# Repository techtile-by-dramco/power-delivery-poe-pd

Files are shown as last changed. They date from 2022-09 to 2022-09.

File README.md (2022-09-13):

# Power delivery board 

This powered device (PD) board is made for the Techtile infrastructure and separates the voltage from the data coming from the ethernet CAT6 24AWG cable. It further converts the voltage to a lower usable 5V voltage with a galvanically isolated dc/dc converter (maximum output power 20W). This board is compatible with the IEEE802.3af/at/bt standard. 

To comply with the IEEE 802.3 standard a delay network was added. This prevents excessive startup power that occurs due to the high input capacitors of the DC/DC converters. During INRUSH state, the power may not exceed Power Class 3 (approximately 13W). Otherwise, the PSE may turn off the PD. (See standard and datasheet NCP1096)

Several USBs and connectors are available to power the peripherals on each tile.

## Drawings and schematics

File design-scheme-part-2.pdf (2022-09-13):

Q2G$1

Q2G$2

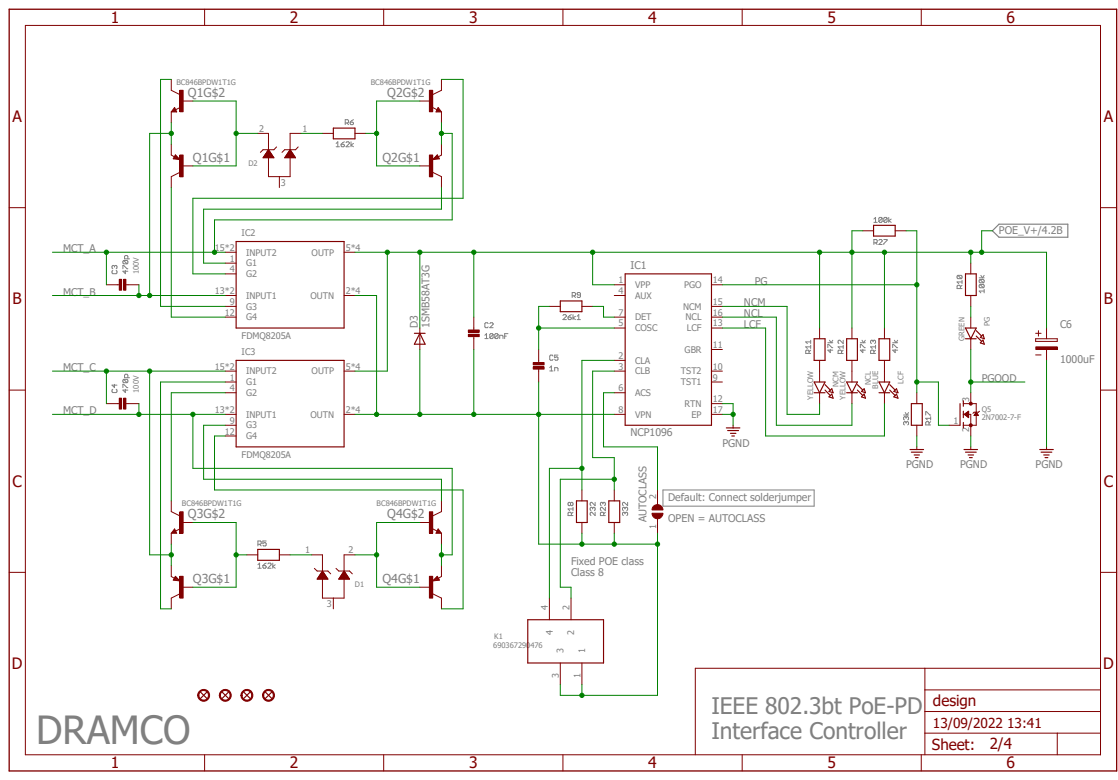
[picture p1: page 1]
NCP1096; BC846BPDW1T1G; BC846BPDW1T1G1SMB58AT3G; 2N7002-7-F PGND; PGND; PGND YELLOW; YELLOW; BLUE; GREEN; 690367290476 ¹⁰⁰V 100V; IEEE 802.3bt PoE-PD DRAMCO; Interface Controller; VPN 8; ACS 6; CLB 3; CLA 2; COSC 5; DET 7; VPP 1; PGO; NCM; NCL; LCF; GBR; AUX 4; RTN; TST2; TST1; INPUT2 15*2; INPUT1 13*2; OUTN; OUTP; FDMQ8205A; 1 2 3 NCM; PG AUTOCLASS 2 1; MCT_C; MCT_D; MCT_A; MCT_B; PGOOD; POE_V+/4.2B; design 13/09/2022 13:41 Sheet: 2/4

Default: Connect solderjumper
OPEN = AUTOCLASS

Fixed POE class
Class 8

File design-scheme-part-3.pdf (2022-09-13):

# 5V Connectors

# 5V FlyBack

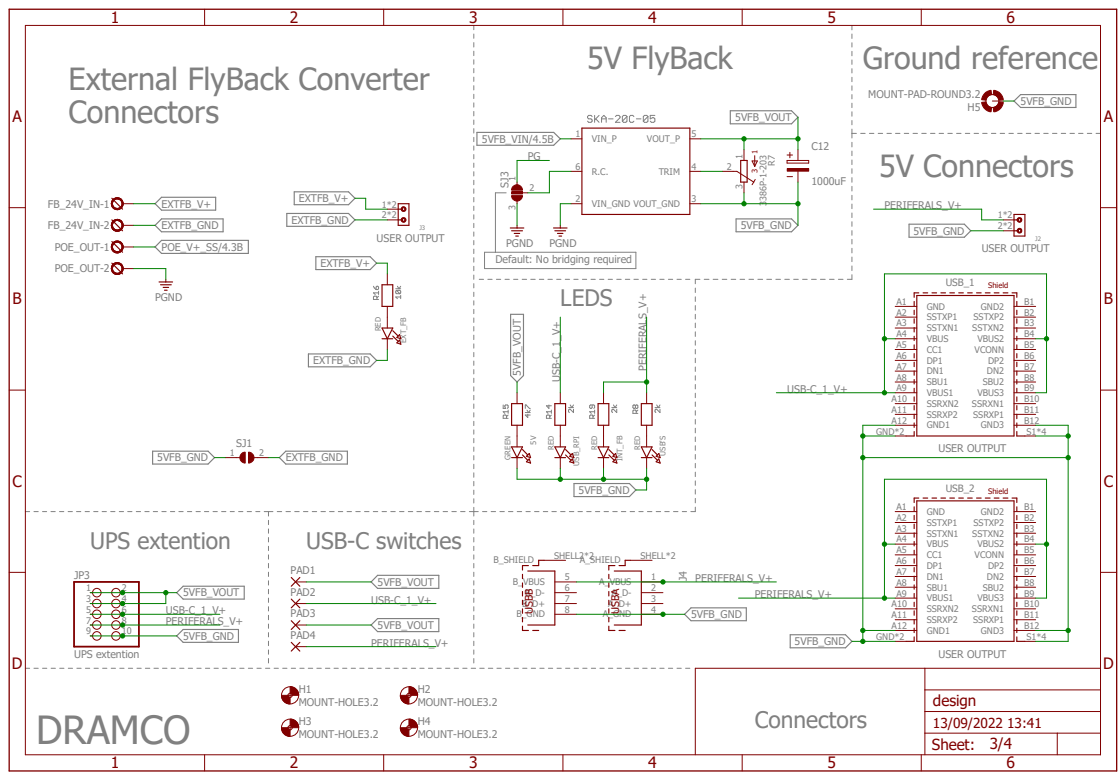
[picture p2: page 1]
MOUNT-HOLE3.2; UPS extention; PGND; 1000uF 3386P⁻1⁻203 RED; RED GREEN; RED; Connectors DRAMCO; USB-C switches; USER OUTPUT; Ground reference; LEDS; USB_1; GND A1 SSTXP1 A2 SSTXN1 A3 VBUS A4 CC1 A5 DP1 A6 DN1 A7 SBU1 A8 VBUS1 A9 SSRXN2 A10 SSRXP2 A11 GND1 A12; GND2; SSRXP1; B11 SSRXN1; VBUS2; SBU2; VCONN; VBUS3; SSTXN2; B3 SSTXP2; GND3; GND*2; USB_2; 1*2 2*2 J2 POE_OUT-1; POE_OUT-2; VIN_P 1; VIN_GND 2; VOUT_P; TRIM; VOUT_GND; C12 R⁷¹ 3; 2 USB'S USB_RPI 5V; H5 EXT_FB; PAD1; PAD2; PAD3; PAD4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

External FlyBack Converter
Connectors

MOUNT-PAD-ROUND3.2 RED
Default: No bridging required

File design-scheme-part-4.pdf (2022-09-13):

A

A

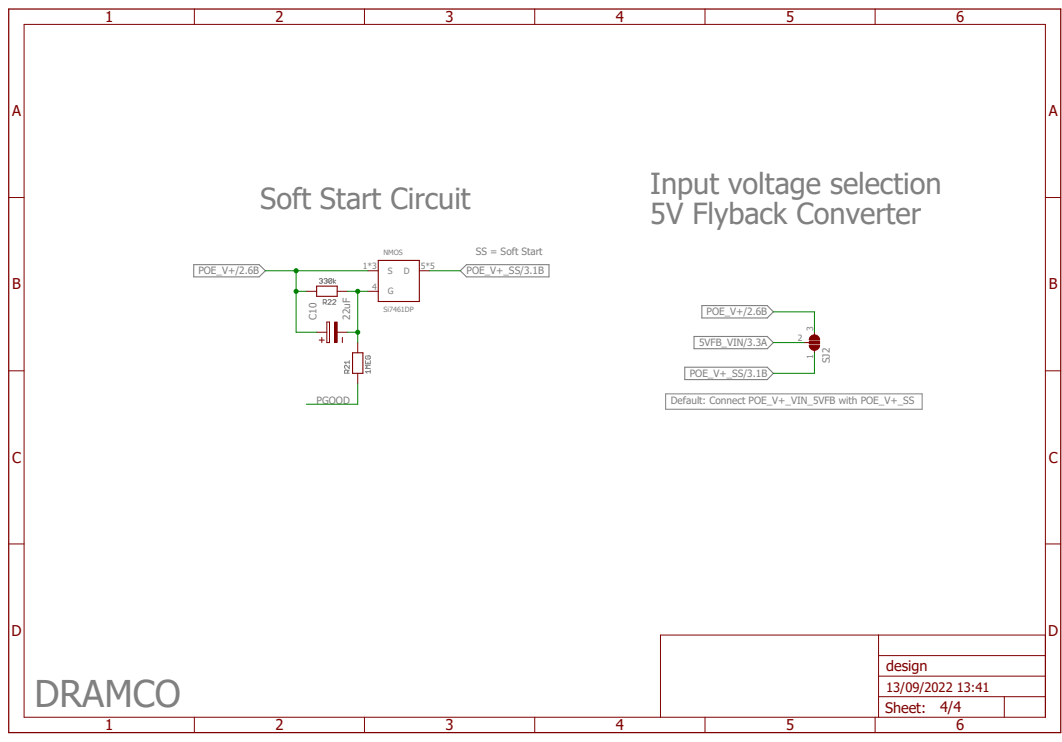
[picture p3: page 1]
DRAMCO; NMOS; POE_V+/2.6B; PGOOD; POE_V+_SS/3.1B; 5VFB_VIN/3.3A; design 13/09/2022 13:41 Sheet: 4/4

Input voltage selection

5V Flyback Converter Soft Start Circuit

SS = Soft Start
POE_V+_SS/3.1B

Default: Connect POE_V+_VIN_5VFB with POE_V+_SS

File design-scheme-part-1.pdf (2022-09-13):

A

A

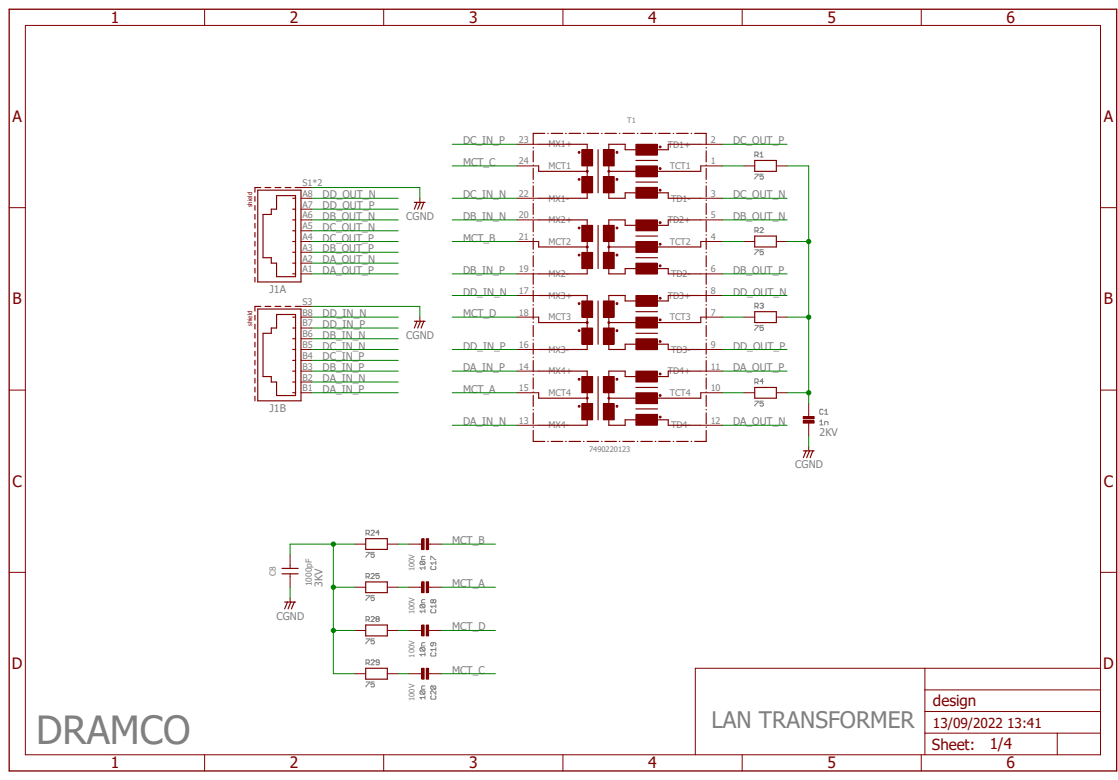
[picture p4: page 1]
CGND; CGND 1000pF; TCT1; MCT1 24; TCT2; MCT2 21; TCT3; MCT3 18; TCT4; MCT4 15; MCT_C; MCT_D; MCT_A; MCT_B; DA_OUT_P; DA_OUT_N; DB_OUT_P; DB_OUT_N; DC_OUT_P; DC_OUT_N; DD_OUT_P; DD_OUT_N DD_OUT_N shield shield; design 13/09/2022 13:41 Sheet: 1/4

LAN TRANSFORMER DRAMCO

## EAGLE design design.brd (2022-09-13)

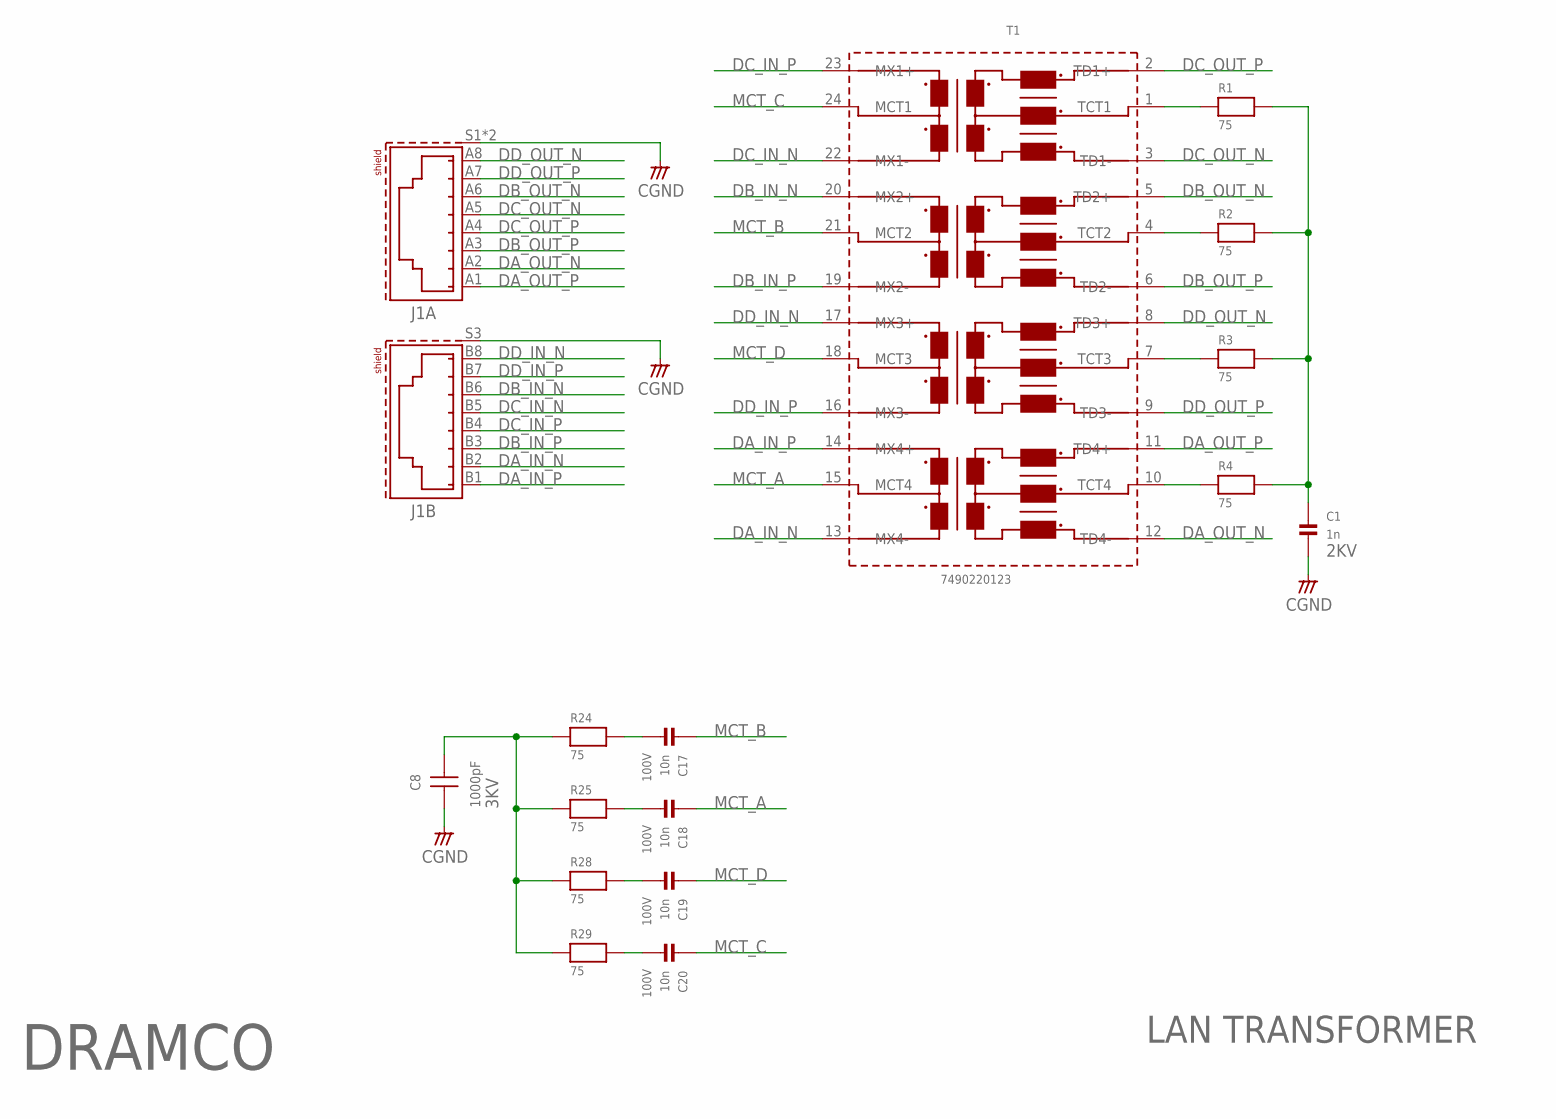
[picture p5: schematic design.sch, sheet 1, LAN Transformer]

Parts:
C1: 1n; 1206
C8: 1000pF; WCAP-CSMH_1808_H2.0
C17, C18, C19, C20: 10n; 0603
J1: 615016137621
R1, R2, R3, R4, R24, R25, R28, R29: 75; 0805
T1: 7490220123; 749022012X

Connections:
CGND: C1.2, C8.1, J1.S1 (SHIELD), J1.S2 (SHIELD), J1.S3 (SHIELD)
DA_IN_N: J1.B2 (7), T1.13 (MX4-)
DA_IN_P: J1.B1 (8), T1.14 (MX4+)
DA_OUT_N: J1.A2 (7), T1.12 (TD4-)
DA_OUT_P: J1.A1 (8), T1.11 (TD4+)
DB_IN_N: J1.B6 (3), T1.20 (MX2+)
DB_IN_P: J1.B3 (6), T1.19 (MX2-)
DB_OUT_N: J1.A6 (3), T1.5 (TD2+)
DB_OUT_P: J1.A3 (6), T1.6 (TD2-)
DC_IN_N: J1.B5 (4), T1.22 (MX1-)
DC_IN_P: J1.B4 (5), T1.23 (MX1+)
DC_OUT_N: J1.A5 (4), T1.3 (TD1-)
DC_OUT_P: J1.A4 (5), T1.2 (TD1+)
DD_IN_N: J1.B8 (1), T1.17 (MX3+)
DD_IN_P: J1.B7 (2), T1.16 (MX3-)
DD_OUT_N: J1.A8 (1), T1.8 (TD3+)
DD_OUT_P: J1.A7 (2), T1.9 (TD3-)
MCT_A: C18.1, T1.15 (MCT4); also elsewhere on the board
MCT_B: C17.1, T1.21 (MCT2); also elsewhere on the board
MCT_C: C20.1, T1.24 (MCT1); also elsewhere on the board
MCT_D: C19.1, T1.18 (MCT3); also elsewhere on the board
unnamed: R4.1, T1.10 (TCT4)
unnamed: R3.1, T1.7 (TCT3)
unnamed: R2.1, T1.4 (TCT2)
unnamed: R1.1, T1.1 (TCT1)
unnamed: C1.1, R1.2, R2.2, R3.2, R4.2
unnamed: C8.2, R24.1, R25.1, R28.1, R29.1
unnamed: C17.2, R24.2
unnamed: C18.2, R25.2
unnamed: C19.2, R28.2
unnamed: C20.2, R29.2

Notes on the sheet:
2KV
3KV
100V
LAN TRANSFORMER
DRAMCO

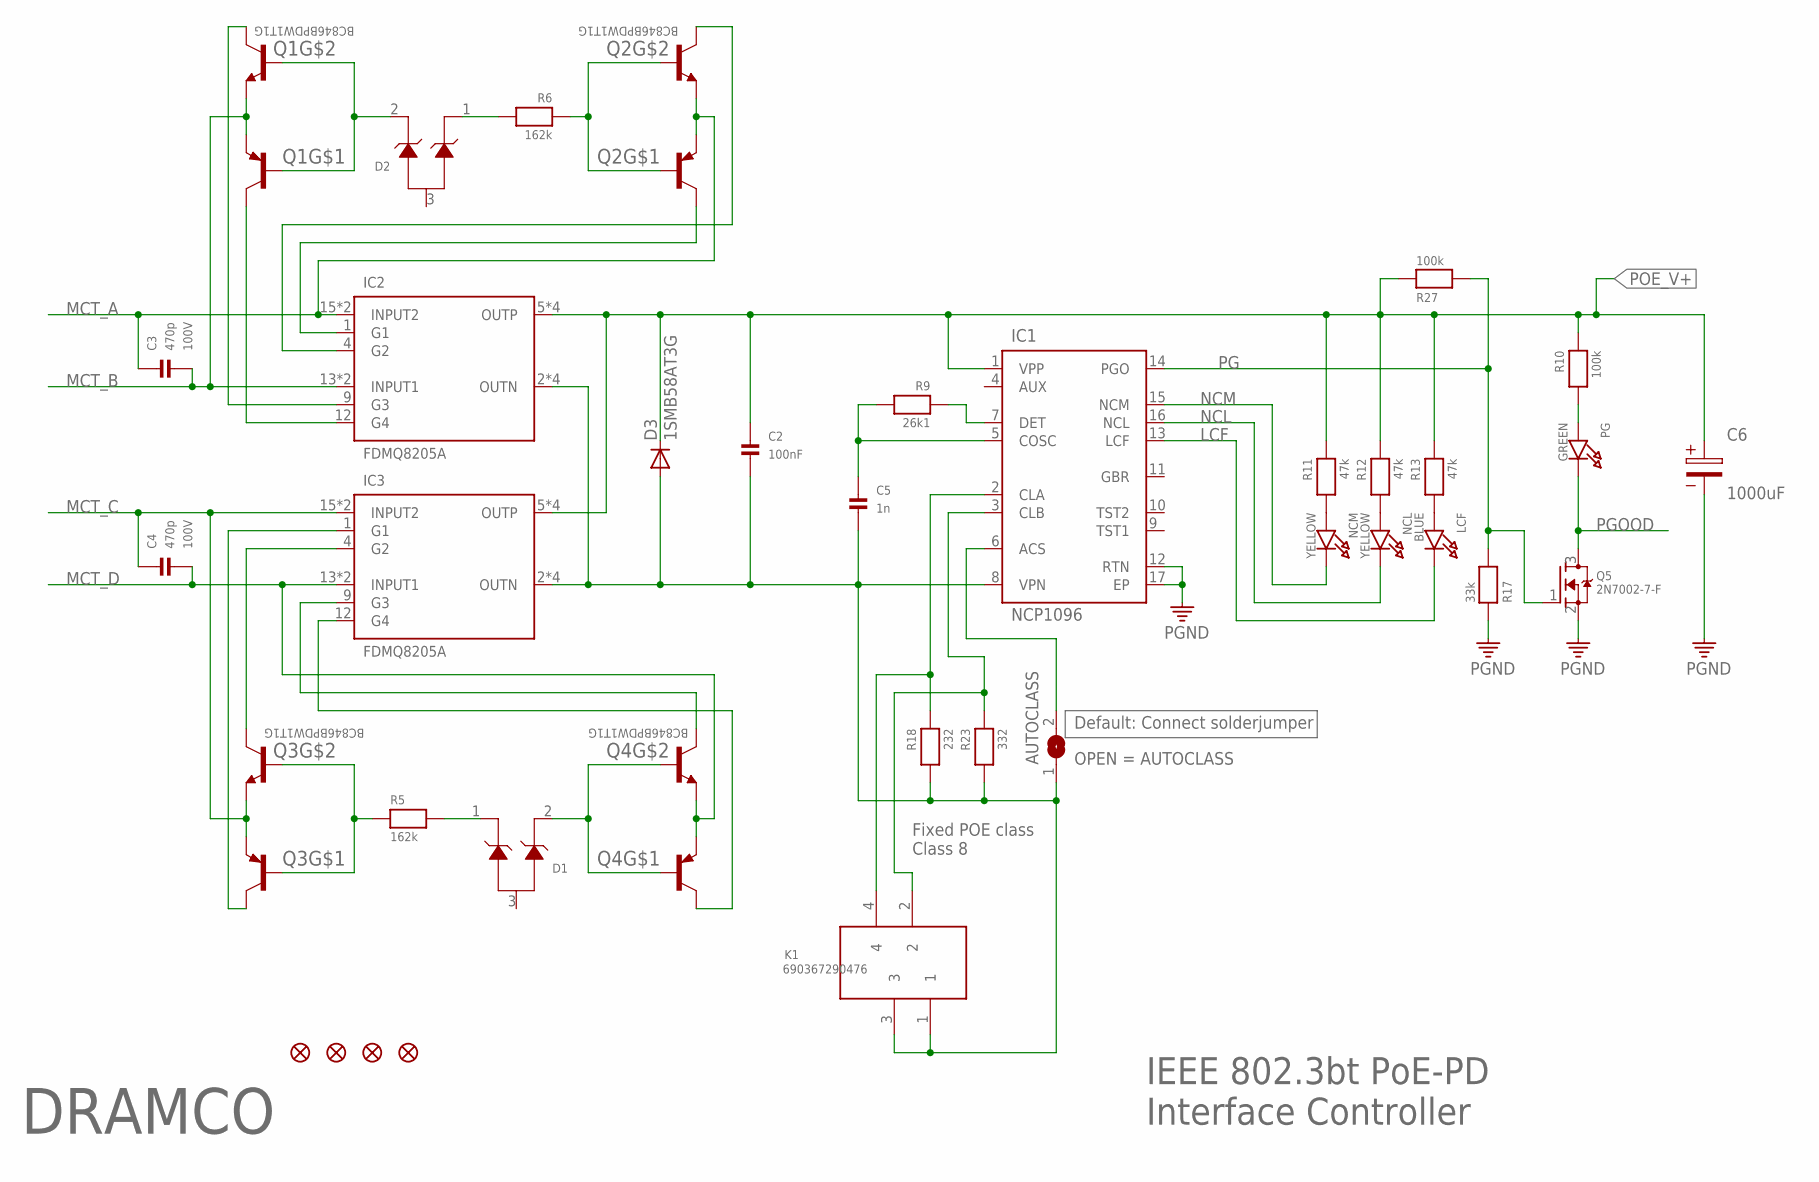
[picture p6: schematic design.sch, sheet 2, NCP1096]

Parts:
AUTOCLASS: SOLDERJUMPERREFLOW; SOLDERJUMPER_REFLOW
C2: 100nF; 0805
C3, C4: 470p; 0603
C5: 1n; 0603
C6: 1000uF; 16X7.5X1.1(DXAXB)
D1, D2: MMBZ27VALT1G; SOT95P237X111-3N
D3: 1SMB58AT3G; DO-214AC
FID1, FID2, FID3, FID5: FIDUCIAL""; FIDUCIAL_1MM
IC1: NCP1096; TSSOP16
IC2, IC3: FDMQ8205A; WDFN-12
K1: 690367290476
LCF: BLUE; CHIPLED_0805
NCL: YELLOW; CHIPLED_0805
NCM: YELLOW; CHIPLED_0805
PG: GREEN; CHIPLED_0805
Q1, Q2, Q3, Q4: BC846BPDW1T1G; SOT65P210X110-6N
Q5: 2N7002-7-F; SOT23-WIDE
R5, R6: 162k; 0603
R9: 26k1; 0603
R10, R27: 100k; 0603
R11, R12, R13: 47k; 0603
R17: 33k; 0603
R18: 232; 0603
R23: 332; 0603

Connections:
LCF: IC1.13 (LCF), LCF.C
MCT_A: C3.1, IC2.15 (INPUT2), IC2.16 (INPUT2), Q2.1 (E2), Q2.4 (E1); also elsewhere on the board
MCT_B: C3.2, IC2.13 (INPUT1), IC2.14 (INPUT1), Q1.1 (E2), Q1.4 (E1); also elsewhere on the board
MCT_C: C4.1, IC3.15 (INPUT2), IC3.16 (INPUT2), Q3.1 (E2), Q3.4 (E1); also elsewhere on the board
MCT_D: C4.2, IC3.13 (INPUT1), IC3.14 (INPUT1), Q4.1 (E2), Q4.4 (E1); also elsewhere on the board
unnamed: IC1.2 (CLA), K1.4, R18.1
unnamed: NCM.A, R11.2
unnamed: IC1.7 (DET), R9.1
unnamed: C5.1, IC1.5 (COSC), R9.2
unnamed: PG.A, R10.2
unnamed: Q3.2 (B2), Q3.5 (B1), R5.1
unnamed: NCL.A, R12.2
unnamed: D1.2, Q4.2 (B2), Q4.5 (B1)
unnamed: IC3.4 (G2), Q3.6 (C2)
unnamed: IC3.1 (G1), Q3.3 (C1)
unnamed: LCF.A, R13.2
unnamed: IC3.12 (G4), Q4.3 (C1)
unnamed: IC3.9 (G3), Q4.6 (C2)
unnamed: Q2.2 (B2), Q2.5 (B1), R6.1
unnamed: IC1.3 (CLB), K1.2, R23.1
unnamed: D1.1, R5.2
unnamed: AUTOCLASS.2, IC1.6 (ACS)
unnamed: D2.2, Q1.2 (B2), Q1.5 (B1)
unnamed: IC2.4 (G2), Q2.6 (C2)
unnamed: IC2.1 (G1), Q2.3 (C1)
unnamed: IC2.12 (G4), Q1.3 (C1)
unnamed: D2.1, R6.2
unnamed: IC2.9 (G3), Q1.6 (C2)
NCL: IC1.16 (NCL), NCL.C
NCM: IC1.15 (NCM), NCM.C
PG: IC1.14 (PGO), Q5.1 (G), R17.2, R27.2; also elsewhere on the board
PGND: C6.2, IC1.12 (RTN), IC1.17 (EP), Q5.2 (S), R17.1; also elsewhere on the board
PGOOD: PG.C, Q5.3 (D); also elsewhere on the board
POE_V+: C2.1, C6.1, D3.C, IC1.1 (VPP), IC2.5 (OUTP), IC2.6 (OUTP), IC2.7 (OUTP), IC2.8 (OUTP), IC3.5 (OUTP), IC3.6 (OUTP), IC3.7 (OUTP), IC3.8 (OUTP), R10.1, R11.1, R12.1, R13.1, R27.1; also elsewhere on the board
VPN: AUTOCLASS.1, C2.2, C5.2, D3.A, IC1.8 (VPN), IC2.2 (OUTN), IC2.3 (OUTN), IC2.10 (OUTN), IC2.11 (OUTN), IC3.2 (OUTN), IC3.3 (OUTN), IC3.10 (OUTN), IC3.11 (OUTN), K1.1, K1.3, R18.2, R23.2

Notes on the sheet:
100V
IEEE 802.3bt PoE-PD Interface Controller
DRAMCO
Fixed POE class Class 8
OPEN = AUTOCLASS
Default: Connect solderjumper

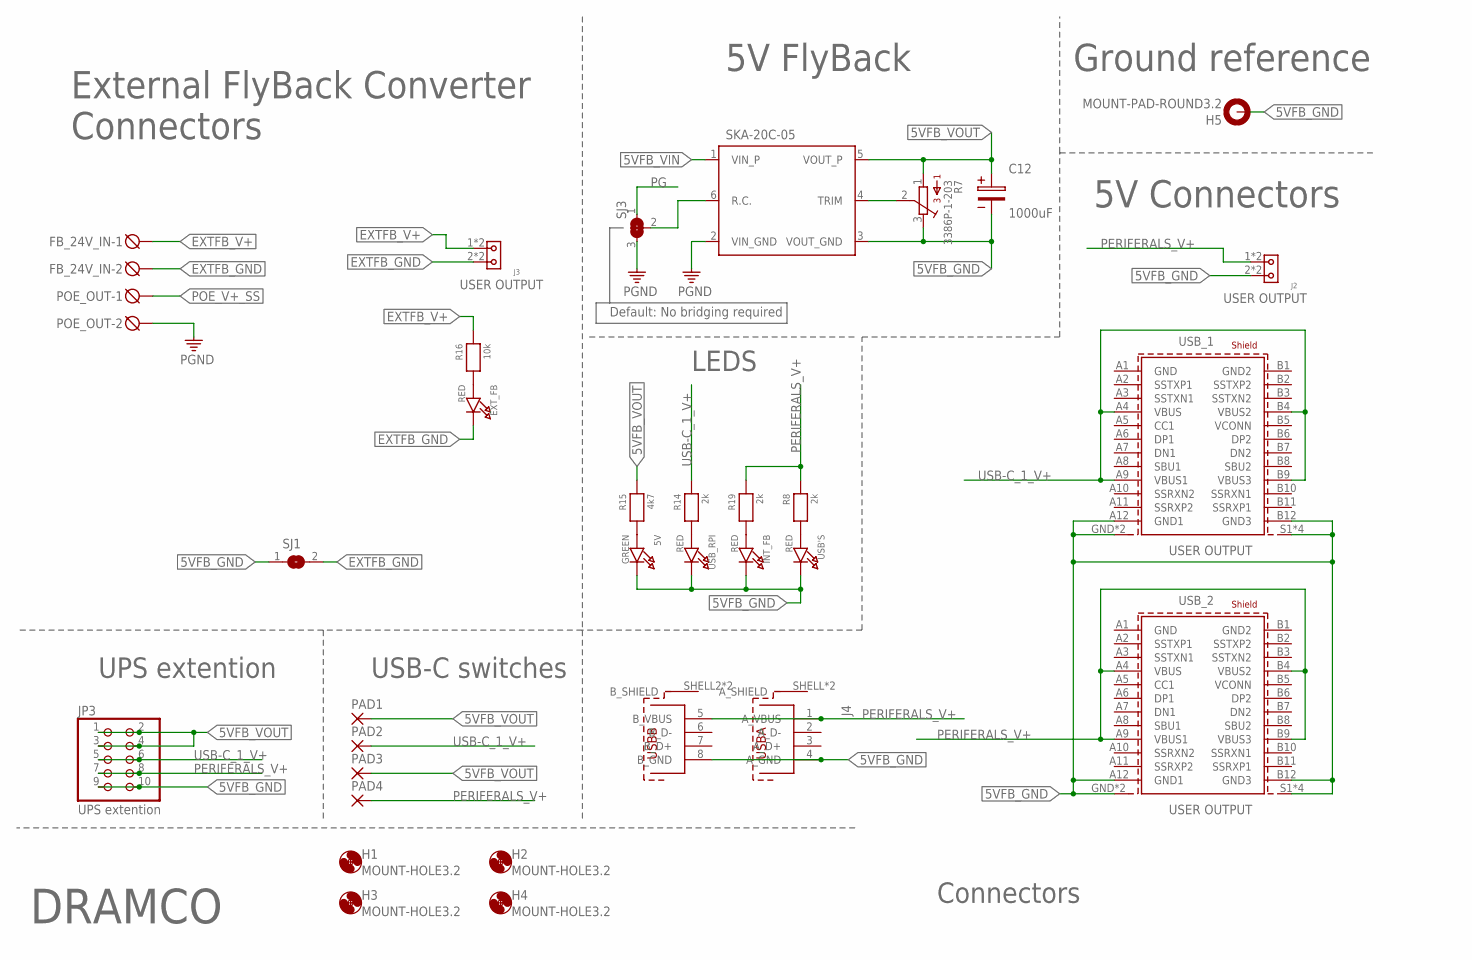
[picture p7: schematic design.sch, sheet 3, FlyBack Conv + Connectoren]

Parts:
5V: GREEN; CHIPLED_0805
C12: 1000uF; 10X5X0.9(DXAXB)
EXT_FB: RED; CHIPLED_0805
FB_24V_IN: DG3XX-02-5.0; DG306-5.0-02P
H1, H2, H3, H4: MOUNT-HOLE3.2; 3,2
H5: MOUNT-PAD-ROUND3.2; 3,2-PAD
INT_FB: RED; CHIPLED_0805
J2, J3: 691411510002
J4: 61400826021
JP3: UPS extention; 2X05
PAD1, PAD2, PAD3, PAD4: SMD5; SMD2,54-5,08
POE_OUT: DG3XX-02-5.0; DG306-5.0-02P
R7: 3386P-1-203; 3386P
R8, R14, R19: 2k; 0603
R15: 4k7; 0603
R16: 10k; 0603
SJ1: SOLDERJUMPERREFLOW; SOLDERJUMPER_REFLOW
SJ3: SOLDERJUMPER_2WAY; SOLDERJUMPER_2WAY_OPEN_NOPASTE
SKA-20C-05: SKA20C-05; SKA20SERIES
USB'S: RED; CHIPLED_0805
USB_1, USB_2: 632723100011
USB_RPI: RED; CHIPLED_0805

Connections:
5VFB_GND: 5V.C, C12.2, H5.B3,2, INT_FB.C, J2.2, J2.A2 (2), J4.4 (A_GND), J4.8 (B_GND), JP3.9, JP3.10, R7.3, SJ1.1, SKA-20C-05.3 (VOUT_GND), USB'S.C, USB_1.A12 (GND1), USB_1.B12 (GND3), USB_1.GND (SHIELD), USB_1.GND1 (SHIELD), USB_1.S1 (SHIELD1), USB_1.S2 (SHIELD1), USB_1.S3 (SHIELD1), USB_1.S4 (SHIELD1), USB_2.A12 (GND1), USB_2.B12 (GND3), USB_2.GND (SHIELD), USB_2.GND1 (SHIELD), USB_2.S1 (SHIELD1), USB_2.S2 (SHIELD1), USB_2.S3 (SHIELD1), USB_2.S4 (SHIELD1), USB_RPI.C
5VFB_VIN: SKA-20C-05.1 (VIN_P); also elsewhere on the board
5VFB_VOUT: C12.1, JP3.1, JP3.2, JP3.3, JP3.4, PAD1.1, PAD3.1, R7.1, R15.1, SKA-20C-05.5 (VOUT_P)
EXTFB_GND: EXT_FB.C, FB_24V_IN.2, J3.2, J3.A2 (2), SJ1.2
EXTFB_V+: FB_24V_IN.1, J3.1, J3.A1 (1), R16.1
unnamed: INT_FB.A, R19.2
unnamed: R8.2, USB'S.A
unnamed: R14.2, USB_RPI.A
unnamed: 5V.A, R15.2
unnamed: EXT_FB.A, R16.2
unnamed: R7.2, SKA-20C-05.4 (TRIM)
unnamed: SJ3.2, SKA-20C-05.6 (R.C.)
PERIFERALS_V+: J2.1, J2.A1 (1), J4.1 (A_VBUS), J4.5 (B_VBUS), JP3.7, JP3.8, PAD4.1, R8.1, R19.1, USB_2.A4 (VBUS), USB_2.A9 (VBUS1), USB_2.B4 (VBUS2), USB_2.B9 (VBUS3)
PG: SJ3.1; also elsewhere on the board
PGND: POE_OUT.2, SJ3.3, SKA-20C-05.2 (VIN_GND); also elsewhere on the board
POE_V+_SS: POE_OUT.1; also elsewhere on the board
USB-C_1_V+: JP3.5, JP3.6, PAD2.1, R14.1, USB_1.A4 (VBUS), USB_1.A9 (VBUS1), USB_1.B4 (VBUS2), USB_1.B9 (VBUS3)

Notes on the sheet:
Connectors
DRAMCO
5V Connectors
5V FlyBack
USB-C switches
External FlyBack Converter Connectors
USER OUTPUT
Ground reference
LEDS
UPS extention
Default: No bridging required

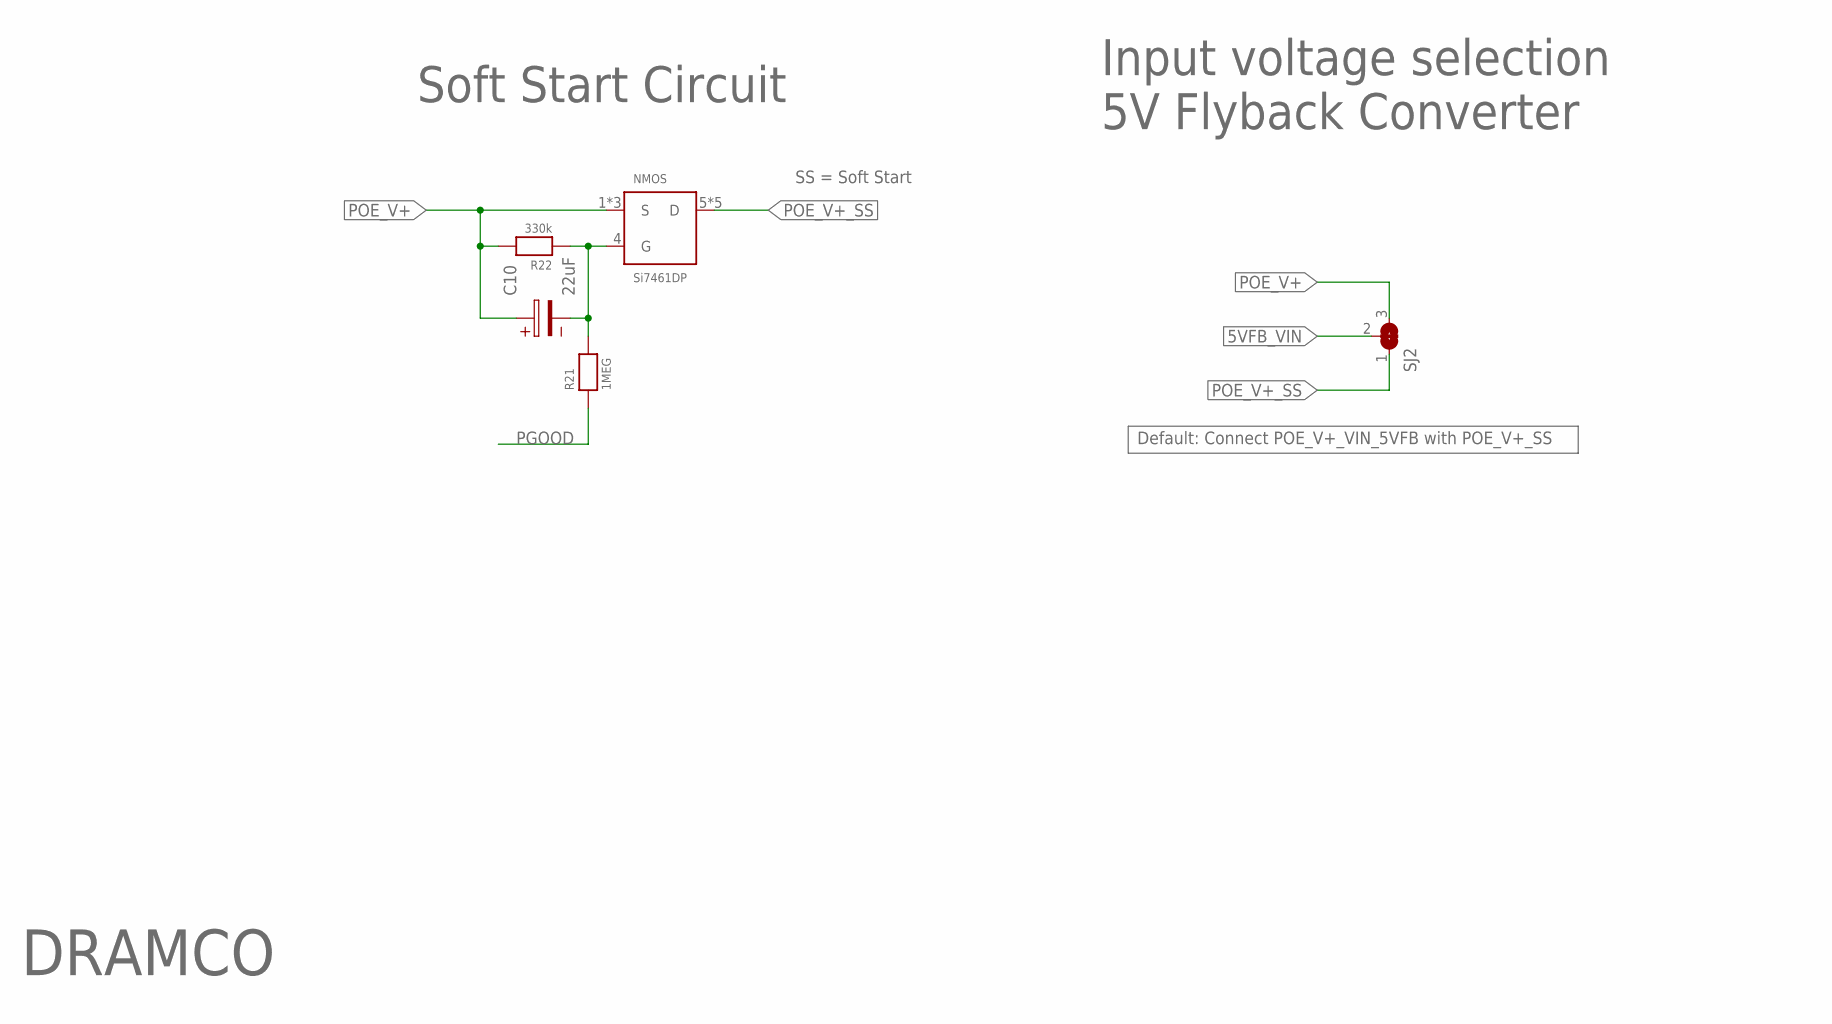
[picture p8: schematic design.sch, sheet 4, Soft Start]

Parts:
C10: 22uF; 5X2X0.8(DXAXB)
NMOS: Si7461DP; SO-8
R21: 1MEG; 0603
R22: 330k; 0603
SJ2: SOLDERJUMPER_2WAY; SOLDERJUMPER_2WAY_OPEN_NOPASTE

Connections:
5VFB_VIN: SJ2.2; also elsewhere on the board
unnamed: C10.2, NMOS.4 (G), R21.2, R22.1
PGOOD: R21.1; also elsewhere on the board
POE_V+: C10.1, NMOS.1 (S), NMOS.2 (S), NMOS.3 (S), R22.2, SJ2.3; also elsewhere on the board
POE_V+_SS: NMOS.5 (D), NMOS.6 (D), NMOS.7 (D), NMOS.8 (D), NMOS.9 (D), SJ2.1; also elsewhere on the board

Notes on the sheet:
DRAMCO
Default: Connect POE_V+_VIN_5VFB with POE_V+_SS
SS = Soft Start
Input voltage selection 5V Flyback Converter
Soft Start Circuit

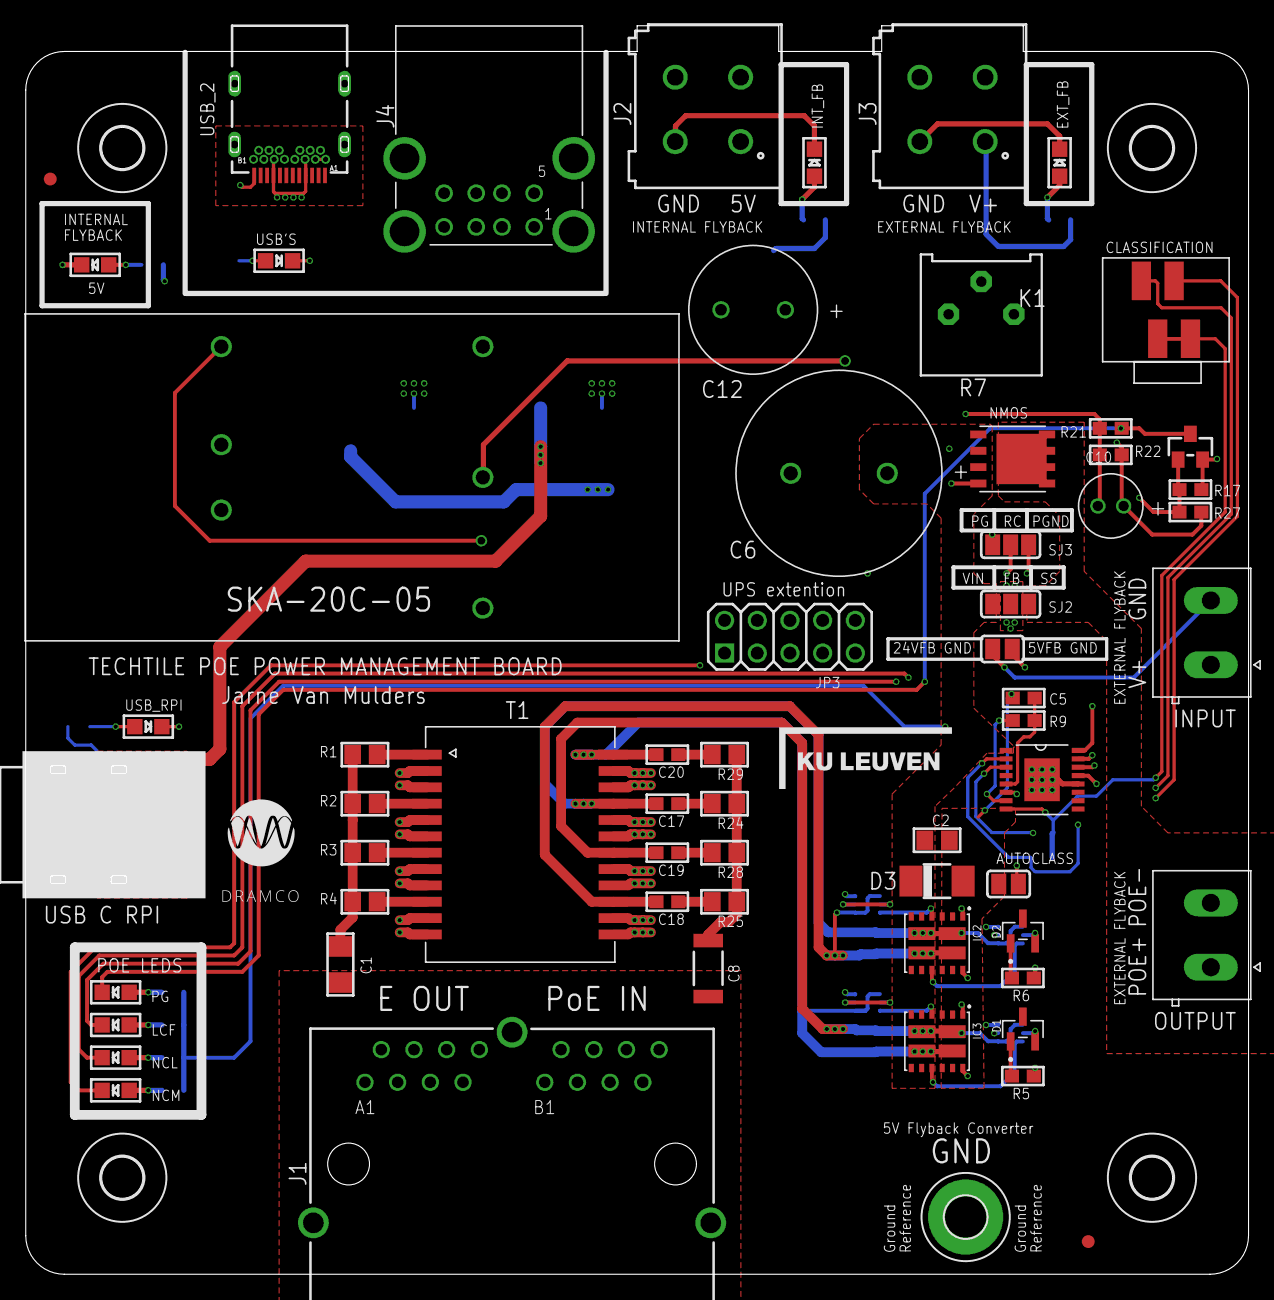
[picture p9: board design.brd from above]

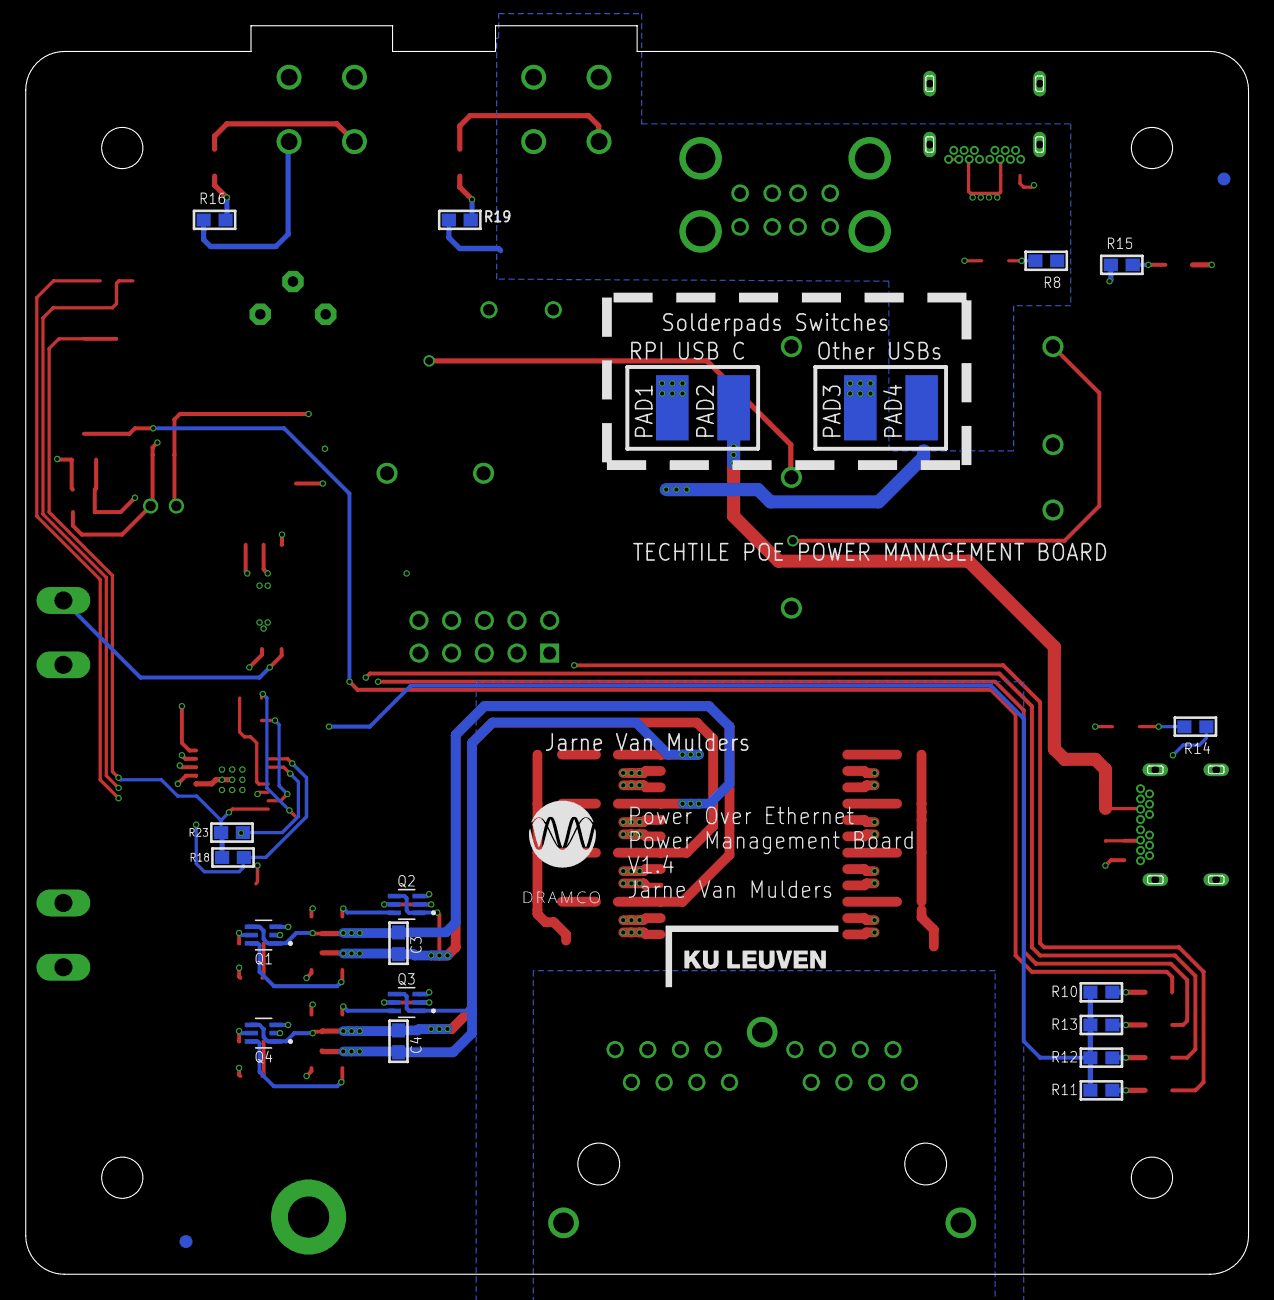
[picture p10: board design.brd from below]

Board: 4 copper layers, 95.0 x 97.0 mm, 90 parts (23 on the bottom side), 78 nets.

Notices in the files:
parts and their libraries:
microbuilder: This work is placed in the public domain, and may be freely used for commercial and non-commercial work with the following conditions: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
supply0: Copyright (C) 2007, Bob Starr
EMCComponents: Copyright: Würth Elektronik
